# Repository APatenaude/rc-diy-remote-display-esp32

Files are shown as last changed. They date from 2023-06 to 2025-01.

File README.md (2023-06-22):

# rc-diy-remote-display-esp32

An ESP32 based dual screen remote display for RaceChrono over BLE

display
demo
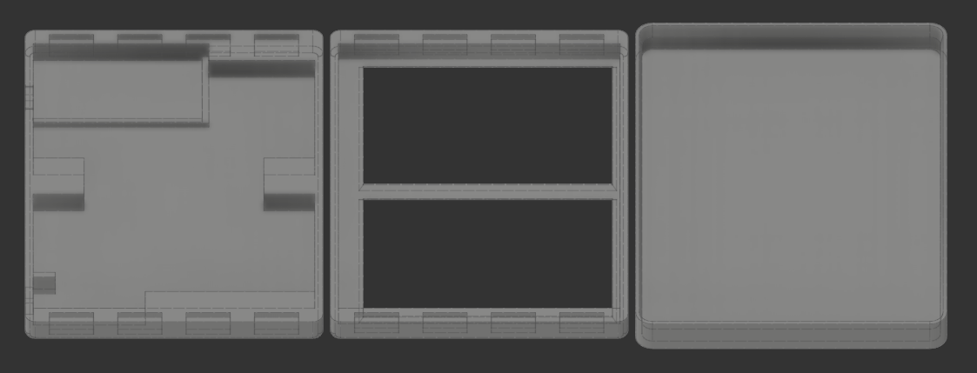
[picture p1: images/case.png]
case


Dimensions :  88mm(W) x 121mm(H) x 16mm(D)

Components :
- Lolin32 lite w/ USB-C
- 2x 3.5 inch 480x320 IPS ILI9488 w/ shortened pcb (https://www.aliexpress.com/item/1005001999296476.html?spm=a2g0o.order_list.order_list_main.28.21ef1802BmLzHp)
- 2100 mah 654060 lipo (power draw is about 300ma so ~7hrs run time)
- SS12F15 Slide Switch
- 3D printed case

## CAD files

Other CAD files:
case/screensv16.f3d

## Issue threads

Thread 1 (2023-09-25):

Shortened PCB

SaLuci, 2023-09-25:
Hey,
Thank you for creating this repo.
Just one question:
How did you shorten the PCB? Did you just cut off the excess PCB?

APatenaude, 2023-09-25:
Basically, yes. The idea is to make the pcb only as big as the screen to minimize space.
I removed the screen from the pcb, removed the sd card reader, cut the excess with a dremel and placed the screen back over the pins.
You need screens with the flex cable going through the pcb, the other designs don't allow you to move the screen towards the pins.

SaLuci, 2023-09-25:
Thank you

Closed 2023-09-25.

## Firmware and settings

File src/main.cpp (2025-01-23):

#include "SPI.h"
#include <esp_system.h>
#include <esp_random.h>
#include <math.h>
#include <FS.h>
#include <Arduino.h>
#include <BLEDevice.h>
#include <BLE2902.h>
#include <TJpg_Decoder.h>
#include "SPIFFS.h"
#include <esp_bt.h>
#include <esp_bt_main.h>
#include <stdio.h>
#include "freertos/FreeRTOS.h"
#include "freertos/task.h"
#include "freertos/event_groups.h"
#include <time.h>
#define LGFX_LOLIN_D32_PRO
#include <config.hpp>
#include <LovyanGFX.hpp>
#include <LGFX_TFT_eSPI.hpp>

#pragma region Data

int lapNumber = 0;
float lapTime = 0;
float prevLapTime = 0;
int bestLapNumber = 0;
float bestLapTime = 0;
float prevSpeedDelta = 0;
float speedDelta = 0;
float prevTimeDelta = 0;
float timeDelta = 0;
float predictedLapTime = 0;
float comparisonLapTime = 0;
bool usingComparisonLap = false;
int satellites = 0;
unsigned long currentTime = 0;
unsigned long previousBatteryIntervalTime = 0;
unsigned long previousTimeIntervalTime = 0;
unsigned long startTime;

float getFastestTime() { return usingComparisonLap && comparisonLapTime > 0 && (bestLapTime == 0 || comparisonLapTime < bestLapTime) ? comparisonLapTime : bestLapTime; }
float getComparisonOrBest() { return usingComparisonLap && comparisonLapTime > 0 ? comparisonLapTime : bestLapTime; }
float isBestFasterThanComparison() { return usingComparisonLap && comparisonLapTime > 0 && bestLapTime > 0 && bestLapTime < comparisonLapTime; }

#pragma endregion Data

#pragma region Config

#define SCREEN1 33
#define SCREEN2 25
#define VBAT_PIN 34
#define RACECHRONO_UUID "00001ff8-0000-1000-8000-00805f9b34fb"
struct MonitoringChannel
{
	bool enabled;
	const char *name;
	const char *formula;
	const float multiplier;
	bool configuring;
	bool configured;
};
MonitoringChannel monitoredChannels[] = {
	/* 0 */ {true, "Lap Number", "channel(device(lap), lap_number)", 1.0, false, false},
	/* 1 */ {true, "Lap Time", "channel(device(lap), lap_time)*1000", 0.001, false, false},
	/* 2 */ {true, "Prev time", "channel(device(lap), previous_lap_time)*1000", 0.001, false, false},
	/* 3 */ {true, "Best lap", "channel(device(lap), best_lap_number)", 1.0, false, false},
	/* 4 */ {true, "Best time", "channel(device(lap), best_lap_time)*1000", 0.001, false, false},
	/* 5 */ {true, "Speed Delta", "channel(device(calc), delta_speed)*100", 0.036, false, false}, // 3.6 multiplier to convert from m/s to km/h
	/* 6 */ {true, "Time Delta", "channel(device(lap), delta_lap_time)*1000", 0.001, false, false},
	/* 7 */ {true, "Comparison time", "channel(device(lap), comparison_lap_time)*1000", 0.001, false, false},
	/* 8 */ {false, "Update Rate", "channel(device(gps), device_update_rate)*10", 0.1, false, false},
	/* 9 */ {true, "Satellites", "channel(device(gps), satellites)", 1.0, false, false},
	/* 10 */ //{false, "Stint", "channel(device(gps), elapsed_time)", 1.0, false, false},
	/* 11 */ //{false, "Speed", "channel(device(gps), speed)*10", 0.36, false, false}, // 3.6 multiplier to convert from m/s to km/h
};
#define SPEED_DELTA_MAX 8
#define SPEED_DELTA_Y 120
const unsigned long batteryLevelDrawInterval = 3000;
const unsigned long stintTimeDrawInterval = 250;
#define SPEED_LINES_COLOR 0xB4B4B4
#define SCREEN2TEXTCOLOR TFT_LIGHTGRAY
const int vref = 1100;
const float voltageCorrectionFactor = 0.975;

#pragma endregion Config

#pragma region Display

TFT_eSPI tft = TFT_eSPI();

bool tft_output(int16_t x, int16_t y, uint16_t w, uint16_t h,
				uint16_t *bitmap)
{
	if (y >= tft.height())
		return 0;
	tft.pushImage(x, y, w, h, bitmap);
	return 1;
}

void selectScreen(uint8_t screen)
{
	if (screen == SCREEN1)
	{
		digitalWrite(SCREEN1, 0); // turn on
		digitalWrite(SCREEN2, 1); // turn off
	}
	else if (screen == SCREEN2)
	{
		digitalWrite(SCREEN1, 1); // turn off
		digitalWrite(SCREEN2, 0); // turn on
	}
}

void screensOn()
{
	// all screens on
	digitalWrite(SCREEN1, 0); // turn on
	digitalWrite(SCREEN2, 0); // turn on
}

void screensOff()
{
	// all screens off
	digitalWrite(SCREEN1, 1); // turn off
	digitalWrite(SCREEN2, 1); // turn off
}

#define STATUS_CONNECTION 1
#define STATUS_CONFIGURATION 2
#define STATUS_DATA 3
int status = 0;
int statusYPos = 1000;
int statusDrawYInterval = 60;
void drawStatus(bool increaseInterval = false, bool clearPrevious = true, int yPos = -1)
{
	if (status == 0)
		return;

	int textWidth = tft.textWidth("waiting for configuration", &fonts::Font4);

	screensOn();
	tft.setTextSize(1);
	tft.setTextPadding(textWidth);
	tft.setTextColor(TFT_WHITE, TFT_BLACK);
	tft.setTextDatum(TC_DATUM);

	if (yPos >= 0)
	{
		if (yPos >= tft.height())
		{
			yPos = yPos - tft.height();
			selectScreen(SCREEN2);
		}
		else
			selectScreen(SCREEN1);
		statusYPos = yPos;
	}
	// move the status around to prevent image retention
	else if (increaseInterval)
	{

		if (clearPrevious)
		{
			tft.fillRect(tft.width() / 2 - textWidth / 2, statusYPos, textWidth, 30, TFT_BLACK);
			tft.setTextColor(TFT_WHITE, TFT_BLACK);
		}

		if (statusYPos + statusDrawYInterval > tft.height() - statusDrawYInterval)
			statusYPos = 10;
		else
			statusYPos += statusDrawYInterval;
	}

	switch (status)
	{
	case 1:
		tft.drawString("waiting for connection", tft.width() / 2, statusYPos, &fonts::Font4);
		break;
	case 2:
		tft.drawString("waiting for configuration", tft.width() / 2, statusYPos, &fonts::Font4);
		break;
	case 3:
		tft.drawString("waiting for data", tft.width() / 2, statusYPos, &fonts::Font4);
		break;

	default:
		break;
	}
}

void clearScreens()
{
	screensOn();
	tft.fillScreen(TFT_BLACK);
}

void drawTimeDelta(float value)
{
	selectScreen(SCREEN1);

	const int color = value >= 0 ? TFT_RED : TFT_GREEN;
	const float deltaAbs = fabs(value);
	const int digits = (deltaAbs >= 1000 ? 0 : (deltaAbs >= 100 ? 1 : (deltaAbs >= 10 ? 2 : 3)));

	tft.setTextSize(1.5);
	tft.setTextPadding(tft.textWidth("88.88", &fonts::Font8));
	tft.setTextColor(color, TFT_BLACK);
	tft.setTextDatum(TC_DATUM);
	tft.drawFloat(deltaAbs, digits, tft.width() / 2, 2, &fonts::Font8);

	tft.setTextSize(3);
	tft.setTextPadding(tft.textWidth("+", &fonts::Font4));
	tft.setTextColor(color, TFT_BLACK);
	tft.setTextDatum(CL_DATUM);
	tft.drawString(value >= 0 ? "+" : "-", 2, 65, &fonts::Font4);
}
void drawTimeDelta()
{
	drawTimeDelta(timeDelta);
}

void drawSpeedDelta(float value, float prevValue)
{
	selectScreen(SCREEN1);

	// could use a sprite instead of this algorithm to avoid flickering but at ~240x480 it would take up a lot of ram

	const int color = value < 0 ? TFT_RED : TFT_GREEN;
	const int width = floor(fabs(value) * (tft.width() / SPEED_DELTA_MAX));
	const int prevColor = prevValue < 0 ? TFT_RED : TFT_GREEN;
	const int prevWidth = floor(fabs(prevValue) * (tft.width() / SPEED_DELTA_MAX));

	if (color == prevColor)
	{
		// if same color and same width, skip
		if (width == prevWidth)
			return;
		// if same color and width greater, draw difference on each side
		else if (width > prevWidth)
		{
			int diff = width - prevWidth;

			// left
			tft.fillRect(ceil((tft.width() - width) / 2), SPEED_DELTA_Y, ceil(diff / 2) + 2, tft.height() - SPEED_DELTA_Y, color);
			// rigth
			tft.fillRect(floor(tft.width() / 2 + prevWidth / 2) - 1, SPEED_DELTA_Y, ceil(diff / 2) + 1, tft.height() - SPEED_DELTA_Y, color);
		}
		// if same color and width smaller, draw black difference on each side
		else
		{
			int diff = prevWidth - width;

			// left
			tft.fillRect(floor((tft.width() - prevWidth) / 2), SPEED_DELTA_Y, ceil(diff / 2) + 1, tft.height() - SPEED_DELTA_Y, TFT_BLACK);
			// rigth
			tft.fillRect(ceil(tft.width() / 2 + width / 2), SPEED_DELTA_Y, ceil(diff / 2) + 2, tft.height() - SPEED_DELTA_Y, TFT_BLACK);
		}
	}
	else
	{
		// if different color, draw over
		tft.fillRect(ceil((tft.width() - width) / 2), SPEED_DELTA_Y, width, tft.height() - SPEED_DELTA_Y, color);

		// if different color and width smaller, draw black difference on each side
		if (width < prevWidth)
		{
			int diff = prevWidth - width;

			// left
			tft.fillRect(floor((tft.width() - prevWidth) / 2), SPEED_DELTA_Y, ceil(diff / 2) + 1, tft.height() - SPEED_DELTA_Y, TFT_BLACK);
			// rigth
			tft.fillRect(floor(tft.width() / 2 + width / 2), SPEED_DELTA_Y, ceil(diff / 2) + 2, tft.height() - SPEED_DELTA_Y, TFT_BLACK);
		}
	}

	int sections = SPEED_DELTA_MAX * 2;
	int spacing = tft.width() / sections;

	for (int i = 0; i <= sections; i++)
	{
		tft.drawLine(i * spacing - (i == sections ? 1 : i == 0 ? -1
															   : 0),
					 tft.height() - (i % (sections / 4) == 0 ? 20 : 12),
					 i * spacing - (i == sections ? 1 : i == 0 ? -1
															   : 0),
					 tft.height(), SPEED_LINES_COLOR);
	}

	tft.setTextSize(1);
	tft.setTextColor(SPEED_LINES_COLOR);
	tft.setTextPadding(0);
	tft.setTextDatum(BL_DATUM);
	tft.drawNumber(SPEED_DELTA_MAX, 1, tft.height() - 20 + 1, &fonts::Font2); // -SPEED_DELTA_MAX
	tft.setTextDatum(BR_DATUM);
	tft.drawNumber(SPEED_DELTA_MAX, tft.width() + 1, tft.height() - 20 + 1, &fonts::Font2); // +SPEED_DELTA_MAX
	tft.setTextDatum(BC_DATUM);
	tft.drawNumber(0, tft.width() / 2 + 1, tft.height() - 20 + 1, &fonts::Font2);								 // 0
	tft.drawNumber(SPEED_DELTA_MAX / 2, (sections / 4) * spacing + 1, tft.height() - 20 + 1, &fonts::Font2);	 // -SPEED_DELTA_MAX/2
	tft.drawNumber(SPEED_DELTA_MAX / 2, (sections / 4) * 3 * spacing + 1, tft.height() - 20 + 1, &fonts::Font2); // +SPEED_DELTA_MAX/2
}
void drawSpeedDelta()
{
	drawSpeedDelta(speedDelta, prevSpeedDelta);
}

std::string getFloatTimeString(float time)
{
	const int minutes = floor(time / 60);
	const int seconds = floor(time - minutes * 60);
	const int milliseconds = fmod(time, 1) * 1000;

	char strBuffer[9];
	snprintf(strBuffer, 9, "%01d:%02d.%03d", minutes, seconds, milliseconds);

	return std::string(strBuffer);
}

std::string getMillisTimeString(int time)
{
	const int minutes = floor(time / 60000);
	const int seconds = floor((time - minutes * 60000) / 1000);
	const int milliseconds = time - minutes * 60000 - seconds * 1000;

	char strBuffer[9];
	snprintf(strBuffer, 9, "%01d:%02d.%03d", minutes, seconds, milliseconds);

	return std::string(strBuffer);
}

void drawLapLabels()
{
	selectScreen(SCREEN2);

	tft.setTextSize(1);
	tft.setTextColor(TFT_WHITE, TFT_BLACK);
	tft.setTextDatum(TL_DATUM);

	tft.setTextPadding(tft.textWidth("Current Lap", &fonts::Font2));
	tft.drawString("Current Lap", 2, 0, &fonts::Font2);

	tft.setTextPadding(tft.textWidth("Predicted Lap", &fonts::Font2));
	tft.drawString("Predicted Lap", 2, 80, &fonts::Font2);

	tft.setTextPadding(tft.textWidth("Previous Lap", &fonts::Font2));
	tft.drawString("Previous Lap", 2, 160, &fonts::Font2);

	tft.setTextPadding(tft.textWidth("Best Lap", &fonts::Font2));
	tft.drawString("Best Lap", 2, 240, &fonts::Font2);

	tft.setTextPadding(tft.textWidth("Lap #", &fonts::Font2));
	tft.drawString("Lap #", 300, 0, &fonts::Font2);

	tft.setTextPadding(tft.textWidth("Stint time", &fonts::Font2));
	tft.drawString("Stint time", 300, 220, &fonts::Font2);

	tft.setTextPadding(tft.textWidth("Best Lap #", &fonts::Font2));
	tft.drawString("Best Lap #", 300, 140, &fonts::Font2);

	tft.setTextPadding(tft.textWidth("Satellites", &fonts::Font2));
	tft.drawString("Satellites", 395, 140, &fonts::Font2);
}

void drawLapNumber(int value)
{
	selectScreen(SCREEN2);

	tft.setTextSize(1.5);
	tft.setTextPadding(tft.textWidth("88", &fonts::Font8));
	tft.setTextColor(SCREEN2TEXTCOLOR, TFT_BLACK);
	tft.setTextDatum(TC_DATUM);
	tft.drawNumber(value, 388, 20, &fonts::Font8);
}
void drawLapNumber()
{
	drawLapNumber(lapNumber);
}

void drawLapTime(float value)
{
	selectScreen(SCREEN2);

	std::string str = getFloatTimeString(value);

	tft.setTextSize(0.75);
	tft.setTextPadding(tft.textWidth("8:88.88", &fonts::Font8));
	tft.setTextColor(SCREEN2TEXTCOLOR, TFT_BLACK);
	tft.setTextDatum(TL_DATUM);
	tft.drawString(str.c_str(), 1, 20, &fonts::Font8);
}
void drawLapTime()
{
	drawLapTime(lapTime);
}

void drawPredictedLapTime(float value)
{
	selectScreen(SCREEN2);

	std::string str = getFloatTimeString(value);

	tft.setTextSize(0.75);
	tft.setTextPadding(tft.textWidth("8:88.88", &fonts::Font8));
	tft.setTextColor(SCREEN2TEXTCOLOR, TFT_BLACK);
	tft.setTextDatum(TL_DATUM);
	tft.drawString(str.c_str(), 1, 100, &fonts::Font8);
}
void drawPredictedLapTime()
{
	drawPredictedLapTime(predictedLapTime);
}

void drawPrevLapTime(float value, bool hightlight)
{
	selectScreen(SCREEN2);

	std::string str = getFloatTimeString(value);

	tft.setTextSize(0.75);
	tft.setTextPadding(tft.textWidth("8:88.88", &fonts::Font8));
	tft.setTextColor(hightlight && getFastestTime() > 0 && prevLapTime <= getFastestTime() ? TFT_GREEN : SCREEN2TEXTCOLOR, TFT_BLACK);
	tft.setTextDatum(TL_DATUM);
	tft.drawString(str.c_str(), 1, 180, &fonts::Font8);
}
void drawPrevLapTime(bool hightlight)
{
	drawPrevLapTime(prevLapTime, hightlight);
}

void drawBestLapTime(float value, bool hightlight)
{
	selectScreen(SCREEN2);

	std::string str = getFloatTimeString(value);

	tft.setTextSize(0.75);
	tft.setTextPadding(tft.textWidth("8:88.88", &fonts::Font8));
	tft.setTextColor(hightlight && isBestFasterThanComparison() ? TFT_GREEN : SCREEN2TEXTCOLOR, TFT_BLACK);
	tft.setTextDatum(TL_DATUM);
	tft.drawString(str.c_str(), 1, 260, &fonts::Font8);
}
void drawBestLapTime(bool hightlight)
{
	drawBestLapTime(getFastestTime(), hightlight);
}

void drawBestLapNumber(int value)
{
	selectScreen(SCREEN2);

	tft.setTextSize(0.75);
	tft.setTextPadding(tft.textWidth("88", &fonts::Font8));
	tft.setTextColor(SCREEN2TEXTCOLOR, TFT_BLACK);
	tft.setTextDatum(TC_DATUM);
	tft.drawNumber(value, 340, 160, &fonts::Font8);
}
void drawBestLapNumber()
{
	drawBestLapNumber(bestLapNumber);
}

void drawSatellites(int value)
{
	selectScreen(SCREEN2);

	tft.setTextSize(0.75);
	tft.setTextPadding(tft.textWidth("88", &fonts::Font8));
	tft.setTextColor(SCREEN2TEXTCOLOR, TFT_BLACK);
	tft.setTextDatum(TL_DATUM);
	tft.drawNumber(value, 395, 160, &fonts::Font8);
}
void drawSatellites()
{
	drawSatellites(satellites);
}

void drawStintTime()
{
	selectScreen(SCREEN2);

	unsigned long time = millis() - startTime;

	const int minutes = floor(time / 60000);
	const int seconds = floor((time - minutes * 60000) / 1000);

	char strBuffer[6];
	snprintf(strBuffer, 6, "%02d:%02d", minutes, seconds);

	tft.setTextSize(0.7);
	tft.setTextPadding(tft.textWidth("88:88", &fonts::Font8));
	tft.setTextColor(SCREEN2TEXTCOLOR, TFT_BLACK);
	tft.setTextDatum(TL_DATUM);
	tft.drawString(strBuffer, 302, 240, &fonts::Font8);
}

#pragma endregion Display

#pragma region Battery

// Array with voltage - charge definitions
float voltageTable[] = {
	3.200, // 0
	3.250, // 1
	3.300, // 2
	3.350, // 3
	3.400, // 4
	3.450, // 5
	3.500, // 6
	3.550, // 7
	3.600, // 8
	3.650, // 9
	3.700, // 10
	3.703, // 11
	3.706, // 12
	3.710, // 13
	3.713, // 14
	3.716, // 15
	3.719, // 16
	3.723, // 17
	3.726, // 18
	3.729, // 19
	3.732, // 20
	3.735, // 21
	3.739, // 22
	3.742, // 23
	3.745, // 24
	3.748, // 25
	3.752, // 26
	3.755, // 27
	3.758, // 28
	3.761, // 29
	3.765, // 30
	3.768, // 31
	3.771, // 32
	3.774, // 33
	3.777, // 34
	3.781, // 35
	3.784, // 36
	3.787, // 37
	3.790, // 38
	3.794, // 39
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
};

int batteryLevel = 0;
int batteryIconIndex = 0;
float batteryVoltage = 0;
const char *batteryImages[] = {
	"/battery_01.jpg",
	"/battery_02.jpg",
	"/battery_03.jpg",
	"/battery_04.jpg",
};

float getVolatge()
{
	return (analogRead(VBAT_PIN) / 4095.0) * 2.0 * 3.3 * (vref / 1000.0) * voltageCorrectionFactor;
}

int getChargeLevel(float volts)
{
	int idx = 50;
	int prev = 0;
	if (volts >= 4.2)
	{
		return 100;
	}
	if (volts <= 3.2)
	{
		return 0;
	}
	while (true)
	{
		int half = abs(idx - prev) / 2;
		prev = idx;
		if (volts >= voltageTable[idx])
		{
			idx = idx + half;
		}
		else
		{
			idx = idx - half;
		}
		if (prev == idx)
		{
			break;
		}
	}
	return idx;
}

void drawBatteryIcon()
{
	selectScreen(SCREEN2);
	TJpgDec.drawFsJpg(tft.width() - 35, tft.height() - 18, batteryImages[batteryIconIndex]);
}

void drawBatteryLevel()
{
	selectScreen(SCREEN2);
	tft.setTextSize(1);
	tft.setTextPadding(tft.textWidth("8.88v", &fonts::Font2));
	tft.setTextColor(TFT_WHITE, TFT_BLACK);
	tft.setTextDatum(BR_DATUM);
	tft.drawString(String(batteryVoltage) + "v", tft.width() - 35, tft.height(), &fonts::Font2);
}

void drawBattery()
{

	batteryVoltage = getVolatge();

	batteryLevel = getChargeLevel(batteryVoltage);
	if (batteryLevel >= 75)
	{
		batteryIconIndex = 3;
	}
	else if (batteryLevel >= 50)
	{
		batteryIconIndex = 2;
	}
	else if (batteryLevel >= 25)
	{
		batteryIconIndex = 1;
	}
	else
	{
		batteryIconIndex = 0;
	}

	drawBatteryIcon();
	drawBatteryLevel();
}

TaskHandle_t drawBatteryAndStatusTaskHandle;
void drawBatteryAndStatusTask(void *pvParameters)
{
	clearScreens();
	while (1)
	{
		if (status > 0)
		{
			drawStatus(true);
		}

		drawBattery();

		vTaskDelay(pdMS_TO_TICKS(batteryLevelDrawInterval));
	}
}

#pragma endregion Battery

TaskHandle_t demoModeTaskHandle;
void demoModeTask(void *pvParameters)
{
	int drawInterval = 100;
	randomSeed(millis());
	float _speedDelta = 0;
	float _prevSpeedDelta = 0;
	int direction = 1;
	int prevBatteryIntervalTime = millis();

	clearScreens();
	drawLapLabels();
	drawBestLapTime(random(0, 600000) / 1000.0, false);
	drawPrevLapTime(random(0, 600000) / 1000.0, false);
	drawBestLapNumber(random(0, 100));
	drawSatellites(random(0, 100));
	drawLapNumber(random(0, 100));
	drawStatus(false, false, 610);

	while (1)
	{

		drawLapTime(random(0, 600000) / 1000.0);
		drawPredictedLapTime(random(0, 600000) / 1000.0);

		drawTimeDelta(random(-10000, 10000) / 1000.0);

		_prevSpeedDelta = _speedDelta;
		if ((_speedDelta >= SPEED_DELTA_MAX) || ((_speedDelta * -1) >= SPEED_DELTA_MAX))
			direction = direction * -1;
		_speedDelta += direction;
		drawSpeedDelta(_speedDelta, _prevSpeedDelta);

		int batteryIntervalDelta = millis() - prevBatteryIntervalTime;
		if (batteryIntervalDelta >= 1000)
		{
			prevBatteryIntervalTime = millis();
			drawBattery();
			drawStintTime();
		}

		// vTaskDelay(pdMS_TO_TICKS(drawInterval));
	}
}

#pragma region BLE

BLEServer *BLE_server = NULL;
BLEService *BLE_service = NULL;
BLECharacteristic *monitorConfigCharacteristic = NULL;
BLECharacteristic *monitorNotificationCharacteristic = NULL;
bool deviceConnected = false;
#define CMD_TYPE_REMOVE_ALL 0
#define CMD_TYPE_REMOVE 1
#define CMD_TYPE_ADD_INCOMPLETE 2
#define CMD_TYPE_ADD 3
#define CMD_TYPE_UPDATE_ALL 4
#define CMD_TYPE_UPDATE 5
#define CMD_RESULT_OK 0
#define CMD_RESULT_PAYLOAD_OUT_OF_SEQUENCE 1
#define CMD_RESULT_EQUATION_EXCEPTION 2
#define MAX_REMAINING_PAYLOAD 2048
#define MAX_PAYLOAD_PART 17
#define MONITOR_NAME_MAX 32
#define MONITORS_MAX 255
bool isConfigured = false;
bool receivedData = false;

void sendConfigCommand(int cmdType, int monitorId, const char *payload, int payloadSequence = 0)
{
	if (!monitoredChannels[monitorId].configuring)
		return;

	// Initially use CMD_TYPE_ADD instead of CMD_TYPE_ADD_INCOMPLETE
	cmdType = cmdType == CMD_TYPE_ADD_INCOMPLETE ? CMD_TYPE_ADD : cmdType;

	// Figure out payload
	char *remainingPayload = NULL;
	char payloadPart[MAX_PAYLOAD_PART + 1];
	if (payload && cmdType == CMD_TYPE_ADD)
	{
		// Copy first 17 characters to payload
		strncpy(payloadPart, payload, MAX_PAYLOAD_PART);
		payloadPart[MAX_PAYLOAD_PART] = '\0';

		// If it does not fit to one payload, save the remaining part
		const int payloadLen = strlen(payload);
		if (payloadLen > MAX_PAYLOAD_PART)
		{
			int remainingPayloadLen = payloadLen - MAX_PAYLOAD_PART;
			remainingPayload = (char *)malloc(remainingPayloadLen + 1);
			strncpy(remainingPayload, payload + MAX_PAYLOAD_PART, remainingPayloadLen);
			remainingPayload[remainingPayloadLen] = '\0';
			cmdType = CMD_TYPE_ADD_INCOMPLETE;
		}
	}
	else
	{
		payloadPart[0] = '\0';
	}

	// Indicate the characteristic
	byte bytes[20];
	bytes[0] = (byte)cmdType;
	bytes[1] = (byte)monitorId;
	bytes[2] = (byte)payloadSequence;
	memcpy(bytes + 3, payloadPart, strlen(payloadPart));

	monitorConfigCharacteristic->setValue(bytes, 3 + strlen(payloadPart));
	monitorConfigCharacteristic->indicate();
	delay(1);

	// Handle remaining payload
	if (remainingPayload)
	{
		sendConfigCommand(CMD_TYPE_ADD, monitorId, remainingPayload, payloadSequence + 1);
		free(remainingPayload);
	}
	else
	{
		Serial.print(monitoredChannels[monitorId].name);
		Serial.println(" configured");
		monitoredChannels[monitorId].configuring = false;
	}
}

void sendUpdateCommand(int monitorId = -1)
{
	// monitorId < 0 means update all
	byte bytes[2];
	if (monitorId < 0)
		bytes[0] = (byte)CMD_TYPE_UPDATE_ALL;
	else
	{
		bytes[0] = (byte)CMD_TYPE_UPDATE;
		bytes[1] = (byte)monitorId;
	}

	monitorConfigCharacteristic->setValue(bytes, 2);
	monitorConfigCharacteristic->indicate();
}

void sendRemoveCommand(int monitorId = -1)
{
	// monitorId < 0 means remove all
	byte bytes[2];
	if (monitorId < 0)
		bytes[0] = (byte)CMD_TYPE_REMOVE_ALL;
	else
	{
		bytes[0] = (byte)CMD_TYPE_REMOVE;
		bytes[1] = (byte)monitorId;
	}

	monitorConfigCharacteristic->setValue(bytes, 2);
	monitorConfigCharacteristic->indicate();
}
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
void loop()
{
	if (deviceConnected && !isConfigured && status == STATUS_CONFIGURATION)
	{
		// continually check if all the channels are configured or configuring
		checkChannelsConfigured();
	}
}

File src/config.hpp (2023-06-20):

#pragma once

#define LGFX_USE_V1

#include <LovyanGFX.hpp>

class LGFX : public lgfx::LGFX_Device
{

    lgfx::Panel_ILI9488 _panel_instance;

    lgfx::Bus_SPI _bus_instance;

public:
    LGFX(void)
    {
        {
            auto cfg = _bus_instance.config();

            cfg.spi_host = VSPI_HOST;
            cfg.spi_mode = 0;
            cfg.freq_write = 40000000;
            cfg.freq_read = 16000000;
            cfg.spi_3wire = true;
            cfg.use_lock = true;
            cfg.dma_channel = SPI_DMA_CH_AUTO;
            cfg.pin_sclk = 4;
            cfg.pin_mosi = 23;
            cfg.pin_miso = -1;
            cfg.pin_dc = 2;

            _bus_instance.config(cfg);
            _panel_instance.setBus(&_bus_instance);
        }

        {
            auto cfg = _panel_instance.config();
            cfg.pin_cs = -1;
            cfg.pin_rst = 18;
            cfg.pin_busy = -1;

            cfg.panel_width = 320;
            cfg.panel_height = 480;
            cfg.offset_x = 0;
            cfg.offset_y = 0;
            cfg.offset_rotation = 0;
            cfg.dummy_read_pixel = 8;
            cfg.dummy_read_bits = 1;
            cfg.readable = true;
            cfg.invert = false;
            cfg.rgb_order = false;
            cfg.dlen_16bit = false;
            cfg.bus_shared = true;

            _panel_instance.config(cfg);
        }

        setPanel(&_panel_instance);
    }
};

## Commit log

2023-06-22 add case
    [screensv16.f3d]
2023-06-27 fix prev lap highlighted after 1st lap
    [main.cpp]
2023-08-31 fix speed delta in RC v8 & prev lap highlight
    [main.cpp]
